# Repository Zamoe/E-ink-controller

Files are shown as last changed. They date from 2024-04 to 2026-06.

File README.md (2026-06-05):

# E-ink-controller

This project uses an e-ink display, buttons and a rotary encoder to create a dymanic smart-home controller. The board connects to WiFi and uses MQTT to connect to a HomeAssistant instance. The E-ink display shows devices being controlled and their current status and the buttons and encoder are used to control the devices. 

## Hardware 

ESP32 DevKit-v1 as the system MCU.
Display is the waveshare 2.13" E-ink Display.
Rotary Knob is the DF Robot Encoder. 
WS2812 Addressable RGB Led Strip.
8 standard buttons are connected to one GPIO pin, using an analog button array configuration. 

See the schematic file for the wiring diagram:
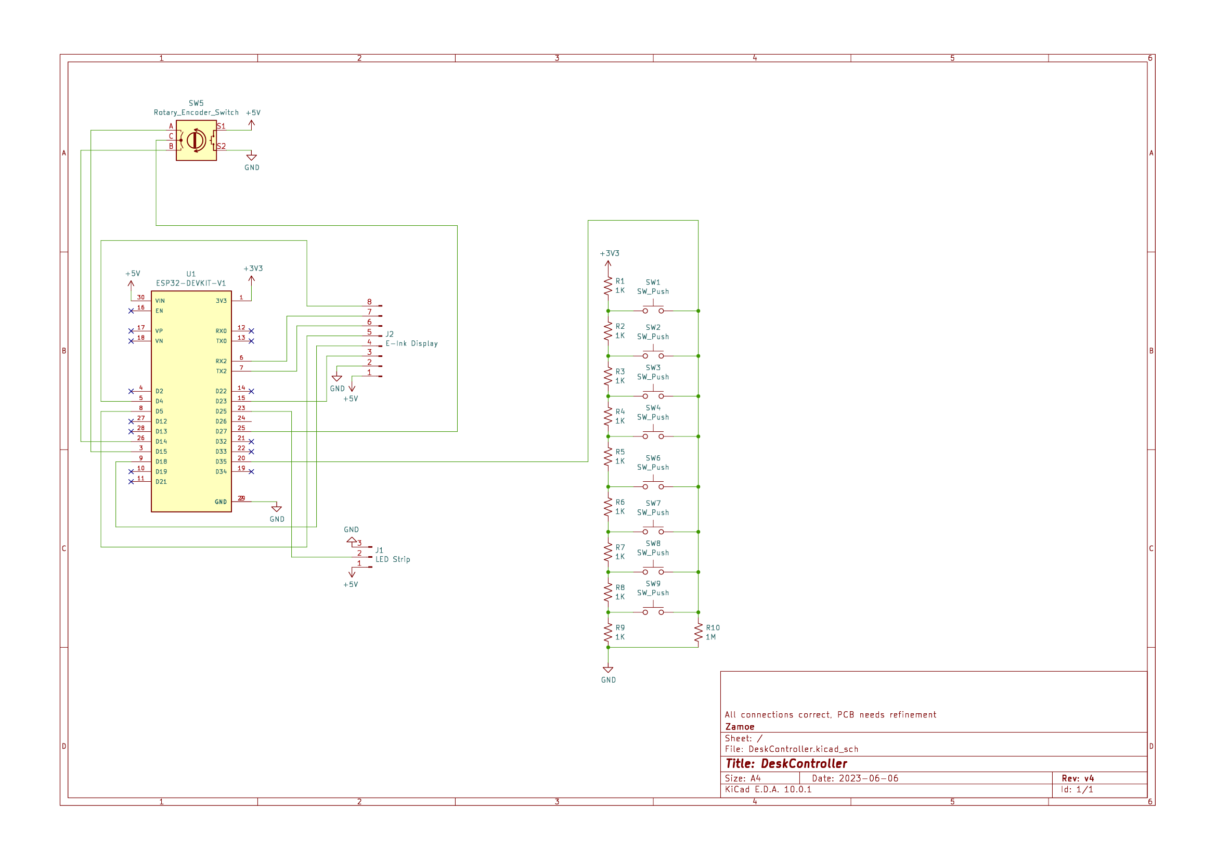
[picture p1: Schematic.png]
Schematic


## Software
The code is constructed using the Arduino IDE with various libraries used for the screen, encoder and buttons. 

## Casing

The 3D print files for the casing can be found in the stl file.

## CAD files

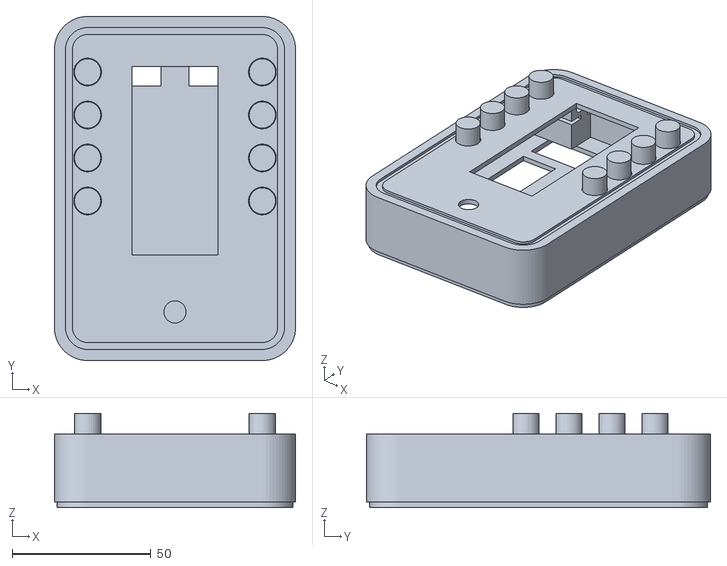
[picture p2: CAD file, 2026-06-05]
Deskcontroller.stl
87.0 x 124.0 x 34.0

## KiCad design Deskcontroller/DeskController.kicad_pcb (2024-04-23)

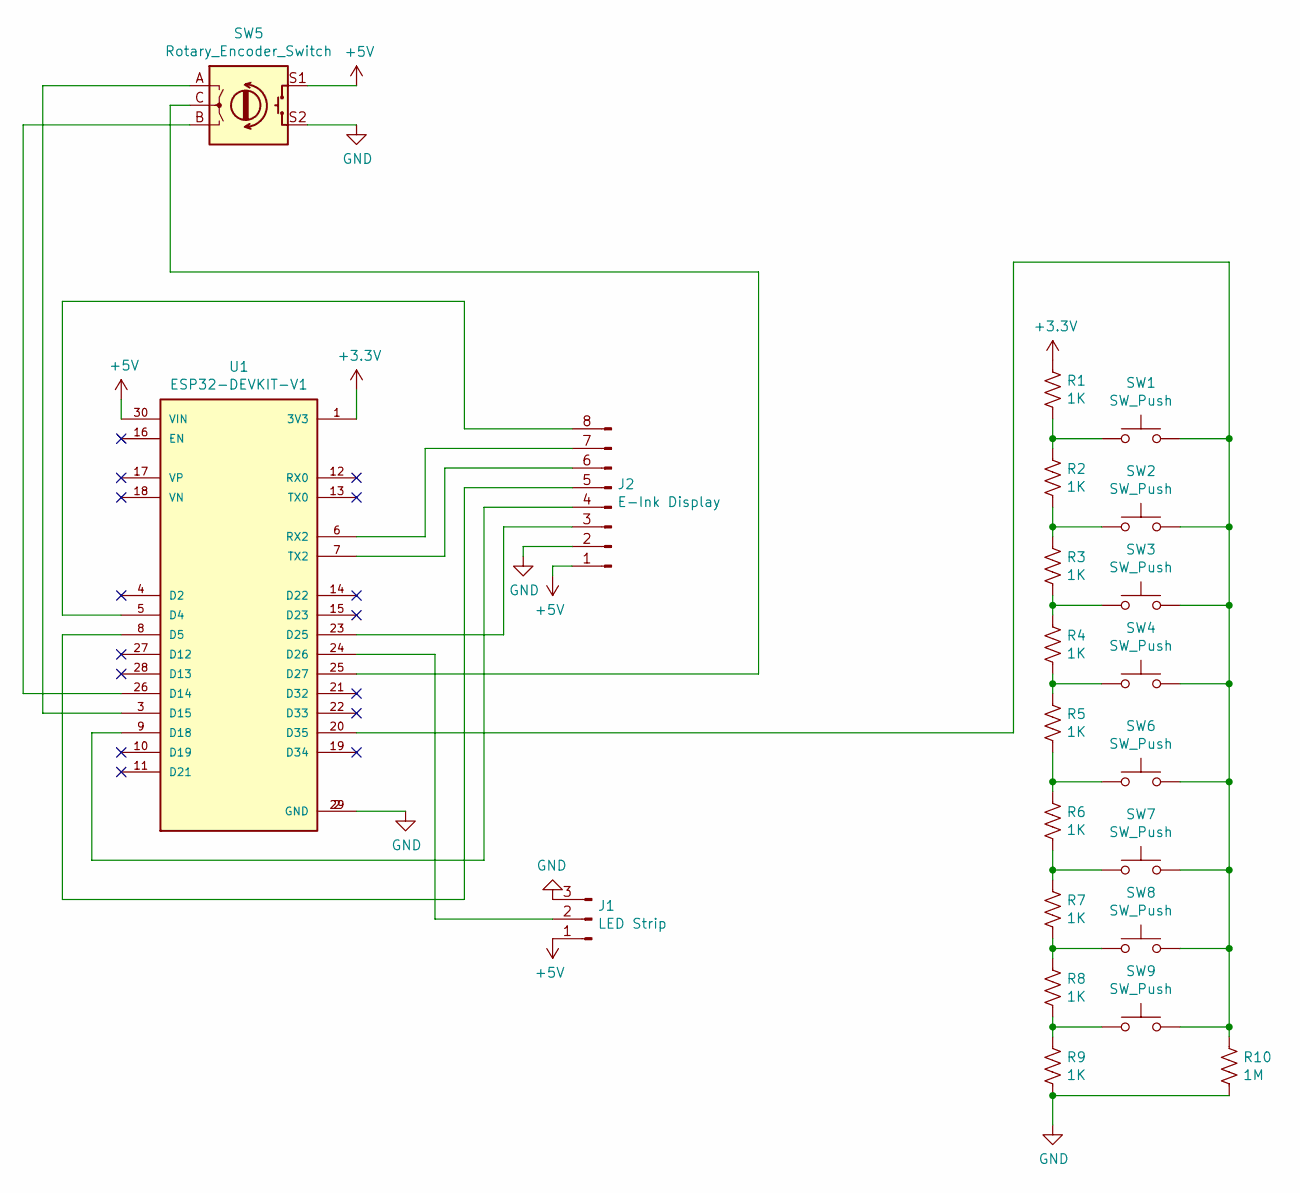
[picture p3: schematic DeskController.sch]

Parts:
J1: LED Strip; JST_GH_BM03B-GHS-TBT_1x03-1MP_P1.25mm_Vertical
J2: E-Ink Display; PinHeader_1x08_P1.27mm_Vertical
R1, R2, R3, R4, R5, R6, R7, R8, R9: 1K; R_Axial_DIN0204_L3.6mm_D1.6mm_P5.08mm_Horizontal
R10: 1M; R_Axial_DIN0204_L3.6mm_D1.6mm_P5.08mm_Horizontal
SW1, SW2, SW3, SW4, SW6, SW7, SW8, SW9: SW_Push; SW_Cherry_MX_1.00u_Plate
SW5: Rotary_Encoder_Switch; RotaryEncoder_Alps_EC11E-Switch_Vertical_H20mm_CircularMoun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
U1: ESP32-DEVKIT-V1; MODULE_ESP32_DEVKIT_V1; PARTREV N/A

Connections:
+3V3: R1.1, U1.1 (3V3)
+5V: J1.1, J2.1, SW5.S1, U1.30 (VIN)
GND: J1.3, J2.2, R9.2, R10.2, SW5.S2, U1.2 (GND), U1.29 (GND)
unnamed: J1.2, U1.24 (D26)
unnamed: J2.3, U1.23 (D25)
unnamed: J2.4, U1.9 (D18)
unnamed: J2.5, U1.8 (D5)
unnamed: J2.6, U1.7 (TX2)
unnamed: J2.7, U1.6 (RX2)
unnamed: J2.8, U1.5 (D4)
unnamed: R1.2, R2.1, SW1.1
unnamed: R2.2, R3.1, SW2.1
unnamed: R3.2, R4.1, SW3.1
unnamed: R4.2, R5.1, SW4.1
unnamed: R5.2, R6.1, SW6.1
unnamed: R6.2, R7.1, SW7.1
unnamed: R7.2, R8.1, SW8.1
unnamed: R8.2, R9.1, SW9.1
unnamed: R10.1, SW1.2, SW2.2, SW3.2, SW4.2, SW6.2, SW7.2, SW8.2, SW9.2, U1.20 (D35)
unnamed: SW5.A, U1.3 (D15)
unnamed: SW5.B, U1.26 (D14)
unnamed: SW5.C, U1.25 (D27)

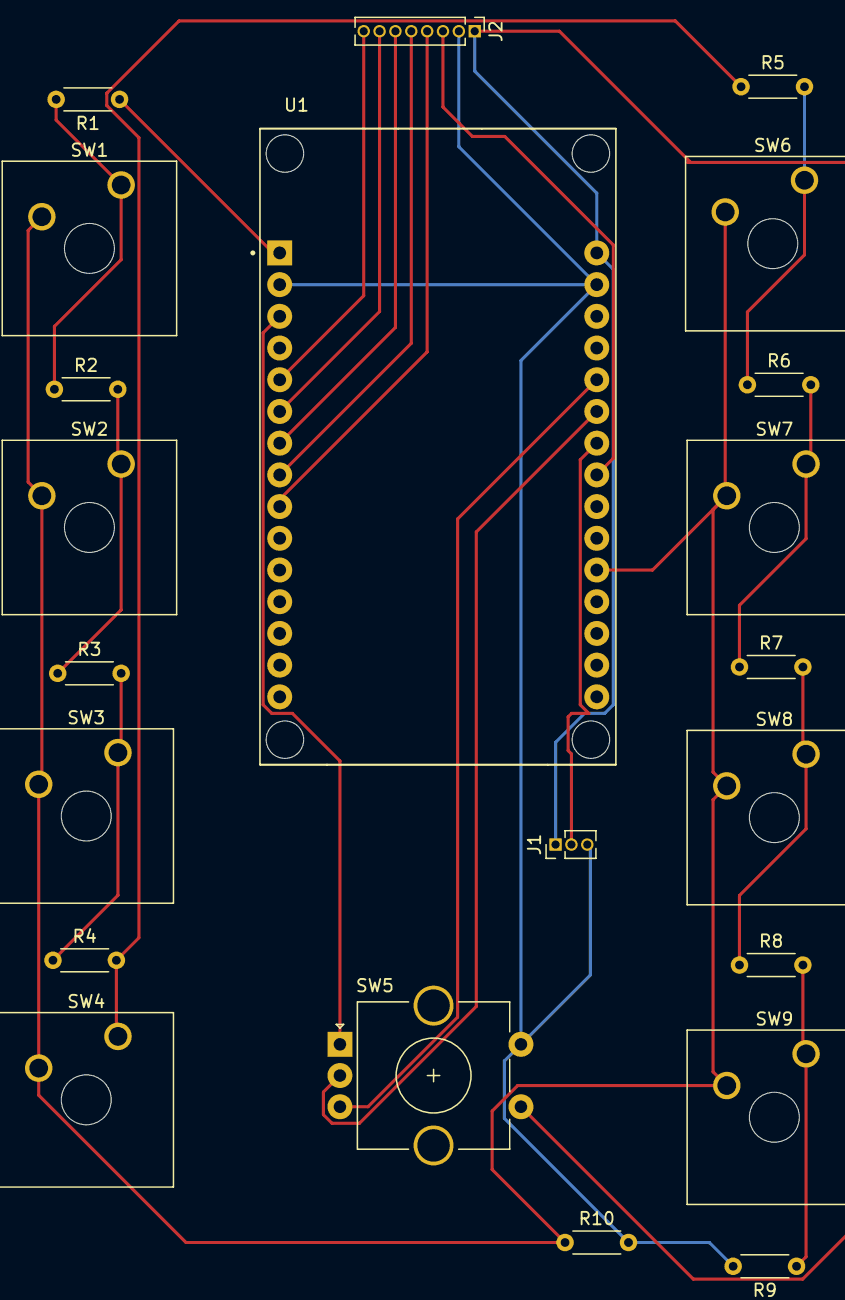
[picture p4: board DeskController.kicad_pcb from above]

Board: 2 copper layers, 22 parts (0 on the bottom side), 22 nets.

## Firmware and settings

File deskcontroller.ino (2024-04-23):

// Rotary Encoder Inputs
#define CLK 14 //B
#define DT 15 //A
#define SW 27  //C

#include "led.h"
#include "rotary.h"
#include "display.h"
#include "mqtt.h"
#include "buttons.h"
#include "settings.h"


int rotState = 0;
//int prevCount = 0;

String mode = "default";

void setup() {
  delay( 3000 ); // power-up safety delay
  pinMode(2, OUTPUT);
  Serial.begin(115200);
  setupLed();
  ledLoop(1);
  setup_wifi();
  ledLoop(2);
  initdisplay(); 
  ledLoop(3);
  setupMQTT();
  ledLoop(4);
  initButtons();
  ledLoop(5);
  initRotBtn();
  ledLoop(6);
  setup_wifi();
  ledLoop(7);
  defaultPage();
  ledLoop(8);
  delay(10);
  ledLoop(10);
  //setupLed();
  FastLED.clear();

  }

void loop(){
  //Serial.println("Program Running");
  if (!client.connected())  // Reconnect if connection is lost
  {
    reconnect();
  }
  client.loop();
  //ledLoop();
  //buttonRead();
  manager.loop();
  rotBtn.read();
  //updateStates();
  int time1 = millis();
  int temp =   rotary();
  mqttRotary(temp);
  /*int count = rotary() + count;
  count = count/4;
  /*if (buttonPressed()== 1){
    Serial.println("buttonPressed");
    digitalWrite(2,HIGH);
    }*/
 // else{digitalWrite(2,LOW);};
  /*if (count != rotState){
     Serial.println(count);
     rotState = count;

  //display
  display.setPartialWindow(5, 10, 50, 50);//x,y,w,h
  display.firstPage();

  do{
    display.setTextColor(GxEPD_BLACK);
    display.fillScreen(GxEPD_WHITE);
    display.setCursor(5, 10);
    display.print(volume);
    Serial.print("volume=");
    Serial.println(volume);
  }while(display.nextPage());
    }
   if (count > prevCount){
    prevCount = count;
    Serial.println("Prev Count increased = %d");
    client.publish("CW", "on");
    Serial.print(prevCount);
    }
  if (count < prevCount){
    prevCount = count;
    Serial.println("Prev Count decreased = %d");
    client.publish("CCW", "on");
    Serial.print(prevCount);
    }*/
   //delay(10);
  /* if (rotButtonRead() == true){
    String test= "";
    Serial.println("Button Pressed long");
    //display.refresh();
    client.publish("room/light", "on");
    Serial.println( " => on");
    //count = 0;
    //buttonState = 0;
    }*/
    
    
   }
  

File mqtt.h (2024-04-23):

#ifndef _mqtt_h
#define _mqtt_h

/******************************************************************************
MQTT_Switch_Example.ino
Example for controlling a light using an MQTT switch
by: Alex Wende, SparkFun Electronics

This sketch connects the ESP32 to a MQTT broker and subcribes to the topic
room/light. When the button is pressed, the client will toggle between
publishing "on" and "off".
******************************************************************************/

#include <WiFi.h>
#include <PubSubClient.h>
#include "settings.h"


// MQTT Network
IPAddress broker(10,0,0,32); // IP address of your MQTT broker eg. 192.168.1.50
WiFiClient wclient;

const char *ID = "DeskController";  // Name of our device, must be unique
const char *TOPIC = "rotarybutton";  // Topic to subcribe to
int SWITCH_PIN = 27;

//State received from HA topics:
const char *BedroomSpeakerVolume = "test/media_player/bedroom_speaker/volume_level";
//const char *subTopic = "test/light/#";

String response;
float volume=0;



PubSubClient client(wclient); // Setup MQTT client
bool state=0;
String prevSpotify = "";
String prevSpotifyArtist = "";
// Handle incomming messages from the broker
void callback(char* topic, byte* payload, unsigned int length) {
  String tempTopic = String(topic);

  for (int i = 0; i < length; i++) {
    response += (char)payload[i];
  }
  Serial.print("Message arrived [");
  Serial.print(topic);
  Serial.print("] ");
  Serial.println(response);
  volume = response.toInt();
  if (ContMode == "default"){
  if (tempTopic == "test/media_player/bedroom_speaker/volume_level"){
      Serial.println("Loop run");
      volume = response.toFloat();
      volume = volume*10;
      ledLoop(volume);
    }
  else if(tempTopic == "test/light/roof_lights/state"){
    if (response == "on"){
      ceilingState = 1;
      }
    else if (response == "off"){
      ceilingState = 0;
      //icons(0,lampx,lampy,backlight);
      }
    else{
      ceilingState = 3;
      }
    icons(ceilingState,ceilingx,ceilingy,ceiling,response);
    }
  else if(tempTopic == "test/light/lamp/state"){
    if (response == "on"){
      lampState = 1;
      //icons(1,lampx,lampy,backlight);
      }
    else if (response == "off"){
      lampState = 0;
      //icons(0,lampx,lampy,backlight,response);
      }
    else{
      lampState = 3;
      }
    icons(lampState,lampx,lampy,lamp,response);
    }
  else if(tempTopic == "test/light/bed/state"){
    if (response == "on"){
      bedState = 1;
      //icons(1,lampx,lampy,backlight,response);
      }
    else if (response == "off"){
      bedState = 0;
      //icons(0,lampx,lampy,backlight);
      }
    else{
      bedState = 3;
      }
    icons(bedState,bedx,bedy,bed,response);
    }
  else if(tempTopic == "test/media_player/samsung_tv_remote/state"){
    if (response == "on"){
      tvState = 1;
      //icons(1,lampx,lampy,backlight,response);
      }
    else if (response == "off"){
      tvState = 0;
      //icons(0,lampx,lampy,backlight);
      }
    else{
      tvState = 3;
      }
    icons(tvState,tvx,tvy,tv,response);
    }
  else if(tempTopic == "test/media_player/samsung_tv_remote/source"){
    if (tvState == 1){
      Serial.println(response);
      response.remove(0,1);
      int len = response.length();
      response.remove(len-1,1);
      tvSource = response;
      Serial.println(tvSource);
      icons(4,tvx,tvy,tv,response);
      }
    }
  else if(tempTopic == "test/light/tv_backlight/state"){
    if (response == "on"){
      backlightState = 1;
      //icons(1,lampx,lampy,backlight);
      }
    else if (response == "off"){
      backlightState = 0;
      //icons(0,lampx,lampy,backlight);
      }
    else{
      backlightState =3;
      }
    icons(backlightState,backlightx,backlighty,backlight,response);
    }
  else if(tempTopic == "test/media_player/spotify_zameer_mahomed/media_title"){
    //if (tvState == 1){
      //Serial.println(response);
      response.remove(0,1);
      int len = response.length();
      response.remove(len-1,1);
      Serial.println(tvSource);
      if(prevSpotify != response){
        //only update display if song changes
        displaySpotify(1,response);
        prevSpotify = response;
        Serial.println("Song Updated");
      }
      //}
    }
  else if(tempTopic == "test/media_player/spotify_zameer_mahomed/media_artist"){
    //if (tvState == 1){
      //Serial.println(response);
      response.remove(0,1);
      int len = response.length();
      response.remove(len-1,1);
      if(prevSpotifyArtist != response){
        displaySpotify(2,response);
        prevSpotifyArtist = response;
        Serial.println("Artist Updated");
      }
    
      //}
    }
  }
  allStatesNew = ceilingState + lampState + backlightState + tvState + bedState;
  response = "";
  
  //updateStates();
}


void mqttRegisterButtons(){
  //registers buttons as sensors in homeassistant
  client.publish("homeassistant/sensor/mode/config","{\"name\":\"Desk Controller Mode\",\"object_id\":\"mode\",\"state_topic\": \"homeassistant/sensor/mode/state\"}",true);
  client.publish("homeassistant/sensor/mode/state", "default");
  client.publish("homeassistant/sensor/left1/config","{\"name\":\"Left 1\",\"object_id\":\"left1\",\"state_topic\": \"homeassistant/sensor/left1/state\"}",true);
  client.publish("homeassistant/sensor/left2/config","{\"name\":\"Left 2\",\"object_id\":\"left2\",\"state_topic\": \"homeassistant/sensor/left2/state\"}",true);
  client.publish("homeassistant/sensor/left3/config","{\"name\":\"Left 3\",\"object_id\":\"left3\",\"state_topic\": \"homeassistant/sensor/left3/state\"}",true);
  client.publish("homeassistant/sensor/left4/config","{\"name\":\"Left 4\",\"object_id\":\"left4\",\"state_topic\": \"homeassistant/sensor/left4/state\"}",true);

  client.publish("homeassistant/sensor/right1/config","{\"name\":\"Right 1\",\"object_id\":\"right1\",\"state_topic\": \"homeassistant/sensor/right1/state\"}",true);
  client.publish("homeassistant/sensor/right2/config","{\"name\":\"Right 2\",\"object_id\":\"right2\",\"state_topic\": \"homeassistant/sensor/right2/state\"}",true);
  client.publish("homeassistant/sensor/right3/config","{\"name\":\"Right 3\",\"object_id\":\"right3\",\"state_topic\": \"homeassistant/sensor/right3/state\"}",true);
  client.publish("homeassistant/sensor/right4/config","{\"name\":\"Right 4\",\"object_id\":\"right4\",\"state_topic\": \"homeassistant/sensor/right4/state\"}",true);

  client.publish("homeassistant/sensor/rotary/config","{\"name\":\"Rotary Encoder\",\"object_id\":\"rotary\",\"state_topic\": \"homeassistant/sensor/rotary/state\"}",true);
  client.publish("homeassistant/sensor/rtbtn/config","{\"name\":\"Rotary Button\",\"object_id\":\"rtbtn\",\"state_topic\": \"homeassistant/sensor/rtbtn/state\"}",true);
  }
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

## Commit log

2024-04-23 Reupload to new git page
    V3.4:
    - LEDs working
    - Rotary working
    - Error in button array
    - Display working
    [Oldbuttons.h, deskcontroller.ino, led.h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]
2024-04-23 Kicad files for PCB design
    [DeskController.kicad_pcb, DeskController.sch, DeskControllerv1-1.kicad_pcb]
